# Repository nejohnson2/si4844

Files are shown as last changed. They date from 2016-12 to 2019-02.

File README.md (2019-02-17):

# SI4844 FM Radio

This is an FM radio using the digital reciever module ```Si4844```. 

- [Si4844 Demo](https://www.silabs.com/documents/public/user-guides/Si4844-B-DEMO.pdf)
- [All About Circuits](http://www.allaboutcircuits.com/projects/build-an-arduino-controlled-am-fm-sw-radio/) - this is the original blog post about setting up radio
- [Design Guide](http://www.silabs.com/Support%20Documents/TechnicalDocs/AN602.pdf)
- [Programming Guide](http://www.silabs.com/Support%20Documents/TechnicalDocs/AN610.pdf)

## STATUS

- [x] Circuit Power
- [x] I2C Communication
- [x] Si4844 power
- [x] FM demodulation
- [x] Basic functionality

To do:
- [ ] Add Band switch
- [ ] Add display
- [ ] On/Off switch
- [ ] Audio out (?)
- [ ] Move to protoboard
- [ ] Enhanced audio amplifier
- [ ] Enhanced AM/FM antenna
- [ ] Buy knobs/dials
- [ ] [Enclosure](https://s-media-cache-ak0.pinimg.com/originals/ba/01/3a/ba013af739433c9e4d94a3727d0fa14c.jpg)

## Build Notes

## Microcontroller 
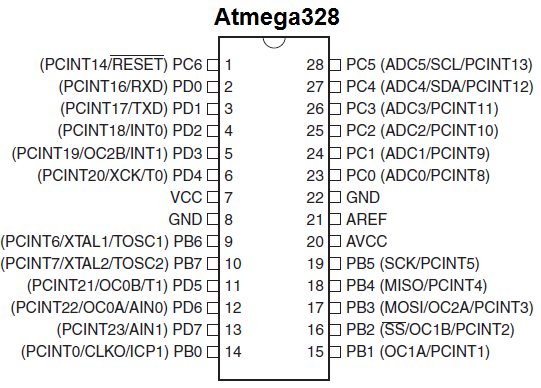
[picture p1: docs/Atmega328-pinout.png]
 ~~The original blog post uses an Arduino 3.3v Pro Mini.  I dont have one of these so instead I'm using a Teensy 3.2.  The main reason I'm going with the Teensy is that it's also a 3.3v board.  I've also thought about using a ```3.3v Trinket Pro``` but I dont have my 3.3v-5v serial adapter.  The ```Teensy 3.2``` has built in serial converter.~~ 

I've decided to get really complicated and use an **ATMEGA328P** chip.  [This page](https://www.arduino.cc/en/Main/Standalone) describes the process of setting up a standalone ATMEGA328P.

## Power
It is suggested to power the whole board from a 3.3v regulator and not the microcontroller as the microcontroller will not supply enough amps.

## Communication
The ```Si4844``` is an I2C slave device with an address ```0x11```.  The ```Si4844``` maximum speed is 50kHz and during some parts of the startup phase, the speed must not exceed 10kHz.  With Arduino, you can use the ```Wire``` library and change the I2C speed with ```Wire.setClock(10000)``` which sets the I2C clock speed to 10k.  I used 2.2k pullup resistors for both the SDA and SCK lines.

## Audio
~~I'm using a basic audio amplifyer circut using the LM386.  The schematic from the datasheet is: ~~

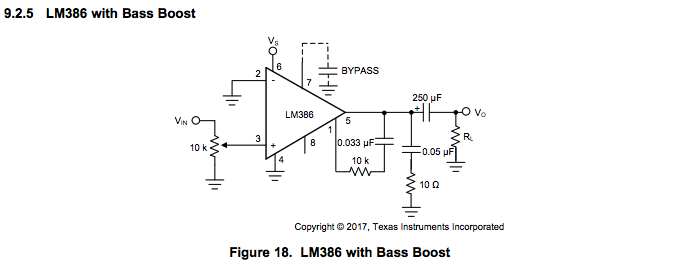
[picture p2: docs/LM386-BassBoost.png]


~~I also used [this website](http://www.circuitbasics.com/build-a-great-sounding-audio-amplifier-with-bass-boost-from-the-lm386/) to enhance the circuit. ~~

The working audio schematic is located [here](https://www.instructables.com/id/Tales-From-the-Chip-LM386-Audio-Amplifier/).

## Antenna
The setup works without any 'official' antenna.  I basically have a 6 inch wire twisted once which is providing quality reception.

## Parts

- [ ] [Si4844-B20](http://www.digikey.com/product-detail/en/silicon-labs/SI4844-B20-GU/SI4844-B20-GU-ND/4069445) - Receiver
- [ ] [TPA3123](http://www.digikey.com/product-detail/en/texas-instruments/TPA3123D2PWPR/296-22008-1-ND/1649103) - Class D Audio Amp

## Final Design

- [ ] On/Off toggle
- [ ] Excellent stereo audio quality
- [ ] Volume knob
- [ ] FM Tuning Knob
- [ ] External antenna option

## Misc Parts

Radio dial inspiration comes from a [1934-36 Zenith 5-S-29](https://s-media-cache-ak0.pinimg.com/564x/3f/08/86/3f08869ec74c9f22957f4a435a4101e7.jpg).  [Here](http://www.radioblvd.com/ZenithPhoto.htm) is a list of all Zenith models.

- [ ] Escutcheone
- [ ] Zenith 6-2-229 Chasis
- [ ] Knobs

### Useful Links

- [Dial Cord String Guide](http://www.theoldradiofixerupperguy.com/dial%20cord.html)
- [Old Radio Zone](http://www.oldradiozone.com/zenith.html)
- [Phil's Old Radios](https://www.antiqueradio.org/wooden.htm)

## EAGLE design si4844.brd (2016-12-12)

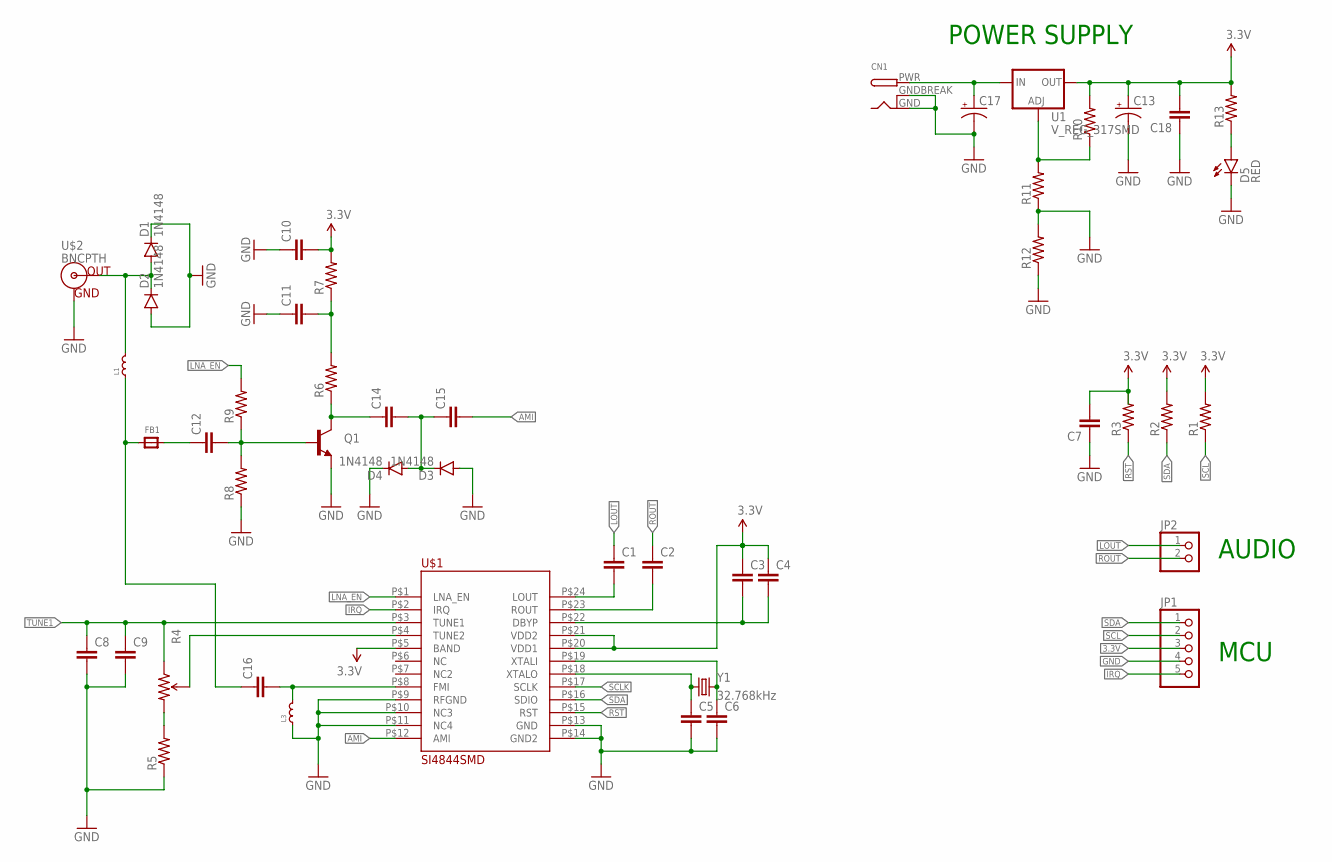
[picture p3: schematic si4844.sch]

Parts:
C1, C2, C3, C4, C5, C6, C7, C8, C9, C10, C11, C12, C14, C15, C16, C18: CAP0603-CAP; 0603-CAP
C13, C17: CAP_POL1206-KIT; EIA3216-KIT
CN1: DCBARRELPTH; DCJACK_2MM_PTH
D1, D2, D3, D4: 1N4148; DIODE-1N4148
D5: RED; LED-1206
FB1: FERRITE_0603; _0603
JP1: HEADER-1X5; 1X05_OVAL
JP2: HEADER-1X2; 1X02_OVAL
L1, L3: RF-INDUCTOR.0603; 0603
Q1: TRANSISTOR_NPNBC547; TO-92-AMMO
R1, R2, R3, R5, R6, R7, R8, R9, R10, R11, R12, R13: RESISTOR0603-RES; 0603-RES
R4: TRIMPOT3362U-2; 3362U-2
U1: V_REG_317SMD; SOT223
U$1: SI4844SMD; SSOP24
U$2: BNCPTH; BNC
Y1: 32.768kHz; CRYSTAL-SMD-3.2X1.5MM

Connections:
3.3V: C3.1, C4.1, C7.2, C10.2, C13.A (+), C18.2, JP1.3, R1.2, R2.2, R3.2, R7.2, R10.2, R13.2, U1.2 (OUT), U$1.P$5 (BAND), U$1.P$20 (VDD1), U$1.P$21 (VDD2)
AMI: C15.2, U$1.P$12 (AMI)
FMI: C16.1, FB1.1, L1.1
GND: C5.2, C6.2, C7.1, C8.2, C9.2, C10.1, C11.1, C13.C (-), C17.C (-), C18.1, CN1.GND, CN1.GNDBREAK, D1.C, D2.A, D3.A, D4.C, D5.C, JP1.4, L3.1, Q1.3 (E), R5.1, R8.1, R11.1, R12.1, R12.2, U$1.P$9 (RFGND), U$1.P$10 (NC3), U$1.P$11 (NC4), U$1.P$13 (GND), U$1.P$14 (GND2), U$2.GND
IRQ: JP1.5, U$1.P$2 (IRQ)
LNA_EN: R9.2, U$1.P$1 (LNA_EN)
LOUT: C1.1, JP2.1
unnamed: C1.2, U$1.P$24 (LOUT)
unnamed: C2.2, U$1.P$23 (ROUT)
unnamed: C3.2, C4.2, U$1.P$22 (DBYP)
unnamed: C5.1, U$1.P$18 (XTALO), Y1.P$1 (1)
unnamed: C11.2, R6.2, R7.1
unnamed: R4.2 (WIPER), U$1.P$4 (TUNE2)
unnamed: C12.2, Q1.2 (B), R8.2, R9.1
unnamed: C6.1, U$1.P$19 (XTALI), Y1.P$2 (2)
unnamed: C14.1, Q1.1 (C), R6.1
unnamed: R4.3 (CW), R5.2
unnamed: C14.2, C15.1, D3.C, D4.A
unnamed: C12.1, FB1.2
unnamed: D1.A, D2.C, L1.2, U$2.S (OUT)
unnamed: C17.A (+), CN1.PWR, U1.3 (IN)
unnamed: C16.2, L3.2, U$1.P$8 (FMI)
unnamed: R10.1, R11.2, U1.1 (ADJ)
unnamed: D5.A, R13.1
ROUT: C2.1, JP2.2
RST: R3.1, U$1.P$15 (RST)
SCL: JP1.2, R1.1
SCLK: U$1.P$17 (SCLK)
SDA: JP1.1, R2.1, U$1.P$16 (SDIO)
TUNE1: C8.1, C9.1, R4.1 (CCW), U$1.P$3 (TUNE1)

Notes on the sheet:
POWER SUPPLY
MCU
AUDIO

Board: 2 copper layers, 47 parts (0 on the bottom side), 29 nets, no tracks yet.

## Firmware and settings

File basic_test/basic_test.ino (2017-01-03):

/*
  SI4844 Basic Test
  Simple test program for the Si4844 Arduino
  AM/FM Radio
  
  Original code from All About Circuits article by Raymond Genovese
  http://www.allaboutcircuits.com/projects/build-an-arduino-controlled-am-fm-sw-radio/
  
  Adapted for Teensy 3.2 by Nicholas Johnson 2017
*/

#include <Wire.h>

// chip I2C address is hard coded
#define Si_ADDRESS 0x11

// Si Commands --------------------------------------
#define ATDD_POWER_DOWN 0x11
#define ATDD_POWER_UP   0xE1
#define GET_REV         0x10
#define ATDD_XOSCEN     0x80
#define ATDD_XOWAIT     0x40
#define ATDD_GET_STATUS 0xE0

// Teensy Setup --------------------------------------
const byte INTpin=2;      // IRQ
const byte RESETpin=12;   // Reset
byte status_rsp[9];
volatile byte IRQflag;

void setup() {
  // set up pins and IRQ
  Serial.begin(115200); 

  pinMode(INTpin, INPUT);      // Interrupt
  pinMode(RESETpin,OUTPUT);     // Reset
  digitalWrite(RESETpin,HIGH);

  attachInterrupt(digitalPinToInterrupt(INTpin),SiISR,RISING);
  Wire.begin();
}

void loop() {
  byte band;
  byte bandmode;
  
  // Note: we are using "Band detection by system controller" mode 
  delay(2000);  // wait for serial monitor click
  Serial.println("*** Si4844 Quick Test **");
  Serial.println("...setting I2C speed to 10kHz");
  I2C_10kHz();
  Serial.println("...resetting Si4844");
  IRQflag=0;
  SiReset();
  
  // wait for an IRQ rising edge
  while(!IRQflag);
  // wait for 2.5 ms
  delayMicroseconds(2500);
  Serial.println("Si4844 reset complete");
  
  band=0;             // FM Band 0 - 87-108 mHz 
  bitSet(band,7);     // bit 7=1 for external crystal
  bitClear(band,6);   // bit 6=0 for normal crystal time
                      // arg[2]-[7] are not used in this mode
  IRQflag=0;
  
  Serial.println("...sending ATDD_POWER_UP with band set");
  
  Wire.beginTransmission(Si_ADDRESS);
  Wire.write(ATDD_POWER_UP);  
  // we are using an external 32.768 crystal (set bit 7)
  // no extra wait time (bit 6 is reset)
  Wire.write(band);
  Wire.endTransmission();
  
  // wait for a powerup IRQ
  while(!IRQflag);
  // wait for 2.5 ms because our IRQ is rising edge
  delayMicroseconds(2500);
  Serial.println("Si4844 ATDD_POWER_UP completed");
  Serial.println("...setting I2C speed to 50kHz");
  I2C_50kHz();
  delayMicroseconds(2000);
  
  // send a get status and wait for 2 ms before testing response byte
  Serial.println("...sending ATDD_GET_STATUS");
  get_status();
  Serial.println("...completed - tuner information is ready");

  // response bytes
  for(int x=0;x<4;x++)
  {
    Serial.print("Response byte ");
    Serial.print(x);
    Serial.print("= ");
    Serial.println(status_rsp[x],BIN);
  }
  
  Serial.print("Band Mode is ");
  bandmode=status_rsp[1]>>6;
  Serial.print(bandmode);
  Serial.println(" [0=FM 1=AM 2=SW]");
  Serial.print("Band Index is ");
  band=status_rsp[1]&B00011111;
  Serial.print(band);
  Serial.println(" [0-19 FM / 20-24 AM / 25-40 SW]");
  
  // print the frequency digits
  Serial.print("Tuner Frequency (mHz)= ");
  Serial.print(status_rsp[2]>>4);
  Serial.print(status_rsp[2]%16);
  Serial.print(status_rsp[3]>>4);
  Serial.print(".");
  Serial.println(status_rsp[3]%16);
  Serial.println();
  Serial.println("Chip information...");
  Wire.beginTransmission(Si_ADDRESS);
  Wire.write(GET_REV);  
  Wire.endTransmission();  
  delay(5);  
  
  Wire.requestFrom(Si_ADDRESS, 0x09);
  for(int x=0;x<9;x++){
    status_rsp[x]=Wire.read();
  }
  IRQflag=0;  
  
  // Tuning Loop --------------------------------------
  Serial.println("Entering tuning loop...");
  IRQflag=0;
  tuneloop:
  if(IRQflag)
   {
     Wire.beginTransmission(Si_ADDRESS);
     Wire.write(ATDD_GET_STATUS);  
     Wire.endTransmission();  
     Wire.requestFrom(Si_ADDRESS, 0x04);
     status_rsp[0]=Wire.read();
     status_rsp[1]=Wire.read();
     status_rsp[2]=Wire.read();
     status_rsp[3]=Wire.read();
     
     // print the frequency digits
     Serial.print(status_rsp[2]>>4);
     Serial.print(status_rsp[2]%16);
     Serial.print(status_rsp[3]>>4);
     Serial.print(".");
     Serial.println(status_rsp[3]%16);
     IRQflag=0;
   }
   goto tuneloop;
}
////////////////////////////////////////////////////////////////////////////////
// Utilities
////////////////////////////////////////////////////////////////////////////////
void SiReset()
{
  // reset Si4844 and back up
  digitalWrite(RESETpin,LOW);
  delayMicroseconds(200);
  digitalWrite(RESETpin,HIGH);
  delayMicroseconds(200);
}

void get_status()
{
  // do SiGetStatus until we have valid frequency info in status_rsp
  // an error out routine can be added here so it can escape
  // after a certain number of attempts
  Waitforgo:               
      SiGetStatus(); 
      if( ((bitRead(status_rsp[0],4)==0) || ( (status_rsp[2]==0) && (status_rsp[3]==0))) )
        {
        goto Waitforgo;       
        }
}

void SiGetStatus()
{
  // send a get status command and wait for 2 ms before testing response byte
  Wire.beginTransmission(Si_ADDRESS);
  Wire.write(ATDD_GET_STATUS);  
  Wire.endTransmission();  
  delayMicroseconds(2000);
  // test response byte
  Wire.requestFrom(Si_ADDRESS, 0x04);
  for(int x=0;x<4;x++)
  {
    status_rsp[x]=Wire.read();
  }
}
////////////////////////////////////////////////////////////////////////////////
// I2C Speed Settings
////////////////////////////////////////////////////////////////////////////////
/*
  NOTE: These speed routines for I2C are for an 8mhz, 3.3v Pro Mini
  They need to be changed for a 16 mHz UNO or other Arduinos
*/
void I2C_10kHz(){
  Wire.setClock(10000);
}
void I2C_50kHz(){
  Wire.setClock(50000);
} 

// The interrupt service routine
void SiISR(){
    IRQflag=1;
}

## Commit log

2016-12-12 init commit
    [si4844.brd, si4844.sch]
2018-02-21 added audio schematics
2019-01-28 updated notes on the audio schematic

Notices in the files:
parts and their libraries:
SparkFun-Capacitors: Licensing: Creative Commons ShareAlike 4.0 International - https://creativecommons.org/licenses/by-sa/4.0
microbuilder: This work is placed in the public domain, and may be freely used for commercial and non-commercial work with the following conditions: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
